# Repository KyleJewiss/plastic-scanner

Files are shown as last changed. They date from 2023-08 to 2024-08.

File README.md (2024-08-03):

# Plastic Scanner

<p align="center">
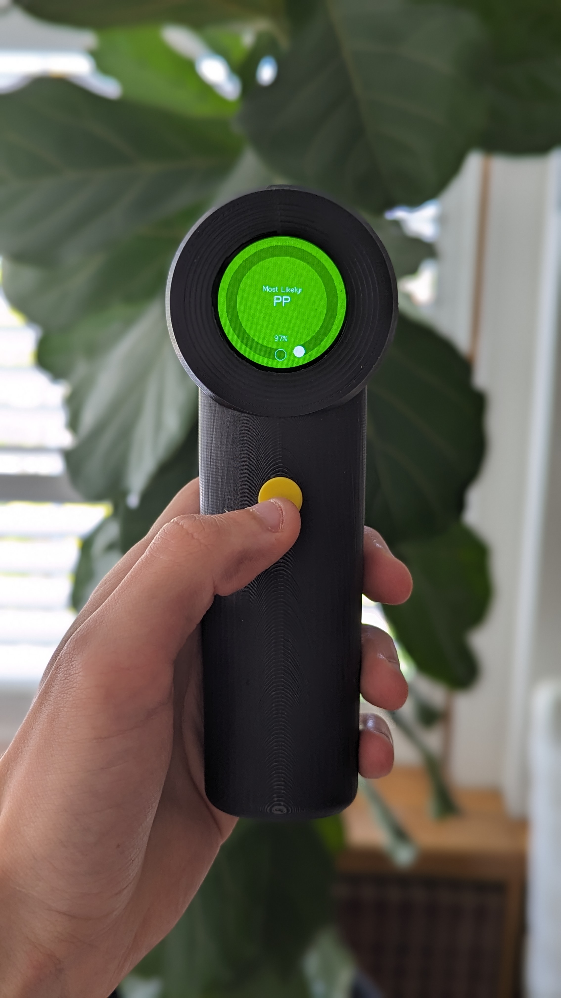
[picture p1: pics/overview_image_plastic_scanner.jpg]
overview_image
  
  overview_image
</p>

## Background
This repo contains the complete work of my Engineering Honours Thesis, 'A Low Cost, Handheld Plastic Identification Device'. This was a continuation of the work produced by the open-source project [Plastic Scanner](https://github.com/Plastic-Scanner). The scanner outlined in this repo can be considered an equal or successor to the [DB2](https://github.com/Plastic-Scanner/DB2.x-Hardware), as this version was used a baseline for the design. This scanner is functional and could be repoduced for testing and development purposes, however it is not adviced to use it in any commercial application. Further development is still needed to improve the reliability of the ML model and the mechanical design.

<p align="center">
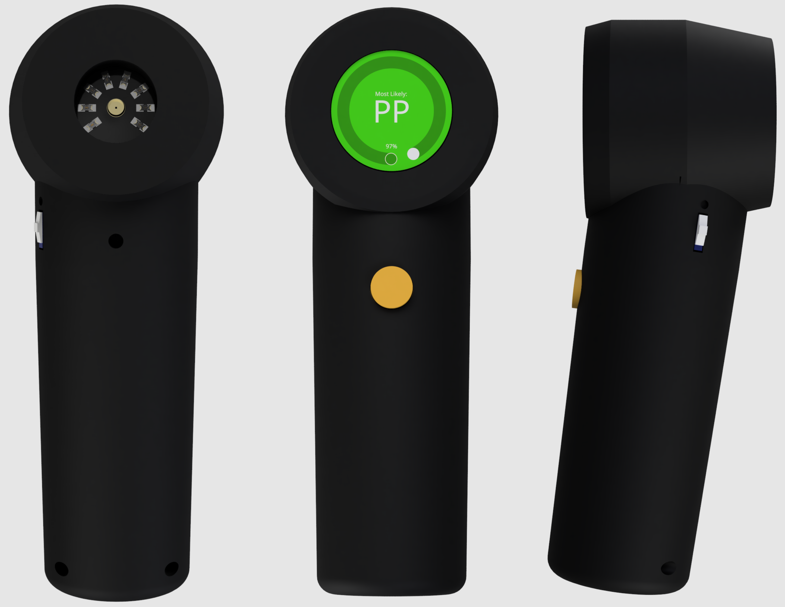
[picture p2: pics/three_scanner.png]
  
</p>

## Introduction
The plastic scanner is a low-cost, handheld device that utilises cheap Infrared (IR) spectroscopic components and a machine learning model to identify plastic polymer types. The device is capable of identifying 7 types of plastics, with a real world accuracy of >80%.

##### Identifiable Plastics
<p align="center">
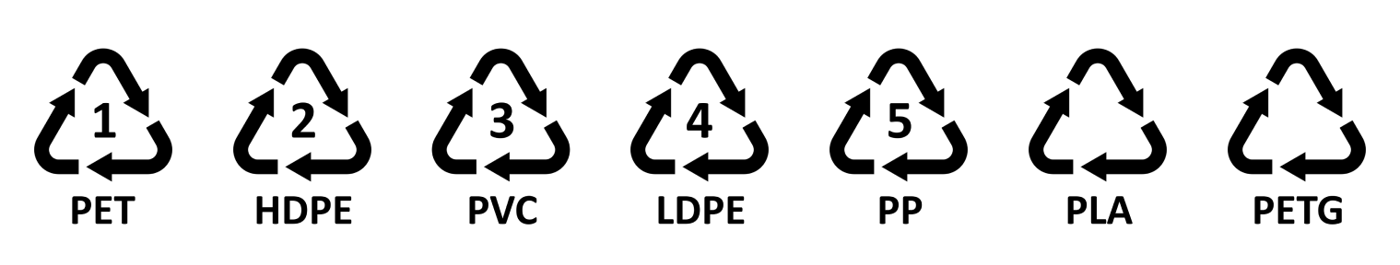
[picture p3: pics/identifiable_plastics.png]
identifiable_plastics
  
</p>

There are some limitations on what it can identify. The scanner is either unable to or struggles to identify plastics that are overly dark/black, very dirty, contain excessive additives, clear or simply too different from the plastic types that were used to train the ML model. For more information on this and much more, checkout [www.plasticscanner.com](www.plasticscanner.com)

## How it works
The scanner works by leveraging principles of [Infrared Spectroscopy](https://en.wikipedia.org/wiki/Infrared_spectroscopy). Plastic polymers tend to have a fairly unqiue reflected waveforms in the IR spectrum, meaning that plastic can be identified/classified by through analysis of these waveforms. The traditional method of achieving this is by using expensive optical filters to obtain the whole reflected intensity waveform. The plastic scanner uses a different approach, it uses relatively inexpensive IR LEDs and a photodiode to obtain the reflected intensities at just a few points. 

<p align="center">
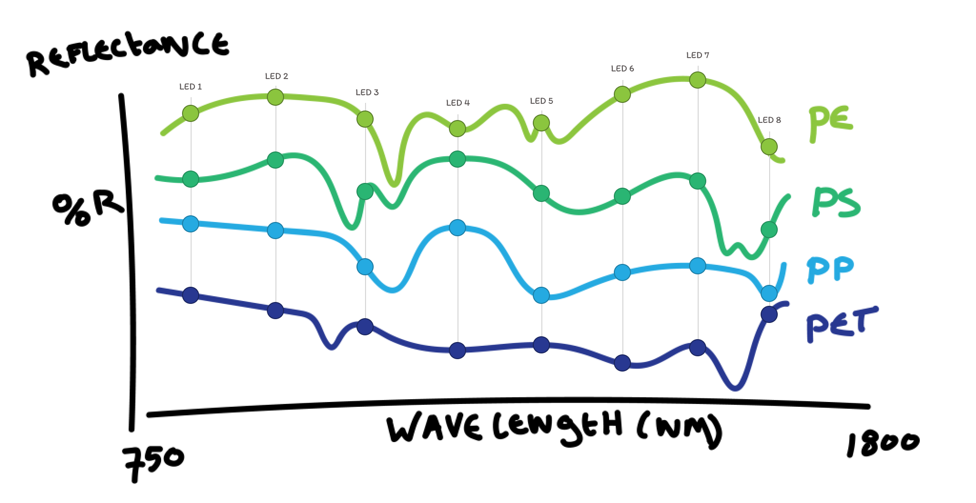
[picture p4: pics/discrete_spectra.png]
discrete_spectra
  
</p>

One at a time, each IR LED is shone onto a plastic sample and an IR photodiode will measure the intensity of the reflected light off of the plastic sample. These 8 intenisty values (one for each LED) can then be fed into an ML model for classification. A novel improvement that this thesis project introduced was to also shine adjacent LEDs at the same time, at half brightness. The light from these two LEDs would then superimpose and provide an additional 7 intensity values, which further improved the accuracy and reliability of the device.

<p align="center">
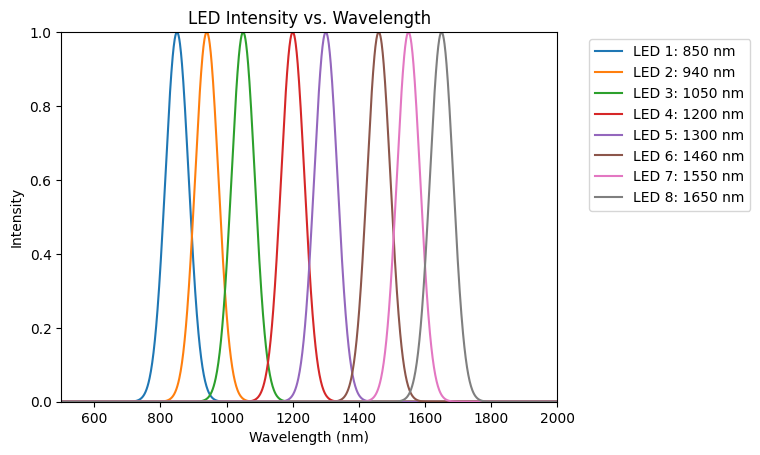
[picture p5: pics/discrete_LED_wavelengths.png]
discrete_LED_wavelengths
  
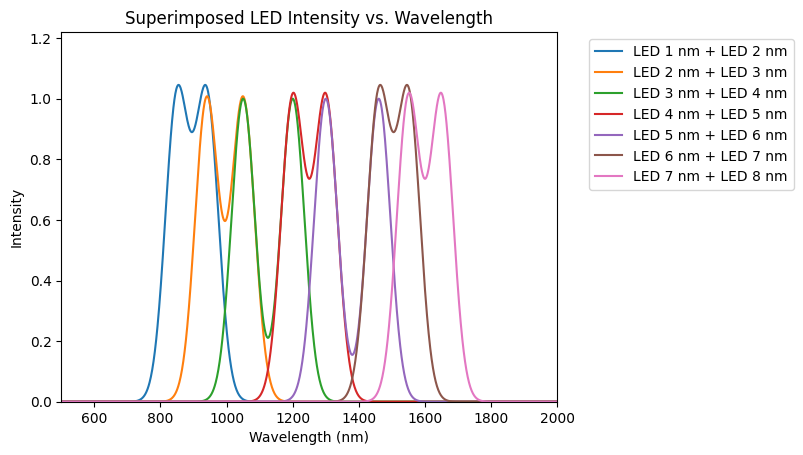
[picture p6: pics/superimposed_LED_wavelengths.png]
superimposed_LED_wavelengths
  
</p>

To identify a piece of plastic, you hold it upto the back of the device (where the LEDs and photodiode is) and press the button. The device will then capture the intensity values, pass them to the ML model and the model will return what it thinks the plastic type most likely is. The round LCD screen on the device will display the predicted polyme type, as well as the associatied percentage likelihood. The following is the 'display guide' for discerning confidence levels.

<p align="center">
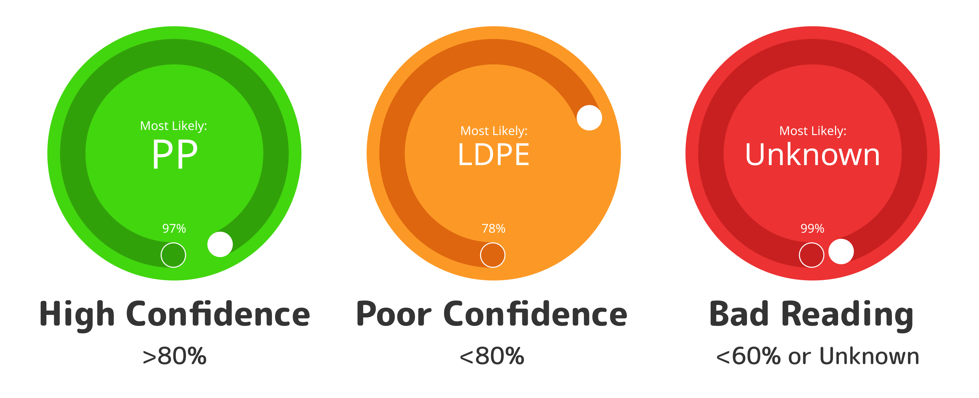
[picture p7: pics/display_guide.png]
display_guide
  
</p>

## Hardware
The custom PCB was designed using EasyEDA, the BOM and GRBL files needed to replicate the board are stored in [hardware/scanninig_PCB](hardware/scanninig_PCB). The structure of the scanner was made in Fusion360 and the CAD files are available. As a brief overview, the device is comprised of the following parts:
- 3D printed enclosure
- Custom scanning PCB
- ESP-32 microcontroller
- 1.28inch Waveshare touchscreen LCD
- 600mAh battery
- Button, switch, USB Typc-C port and fasteners 

<p align="center">
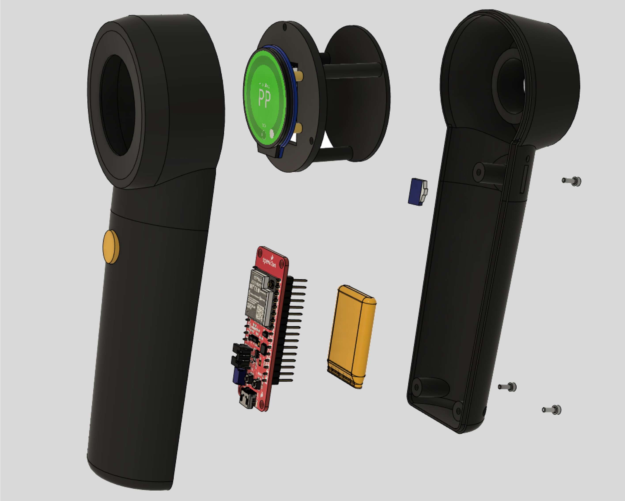
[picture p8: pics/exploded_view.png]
exploded_view
  
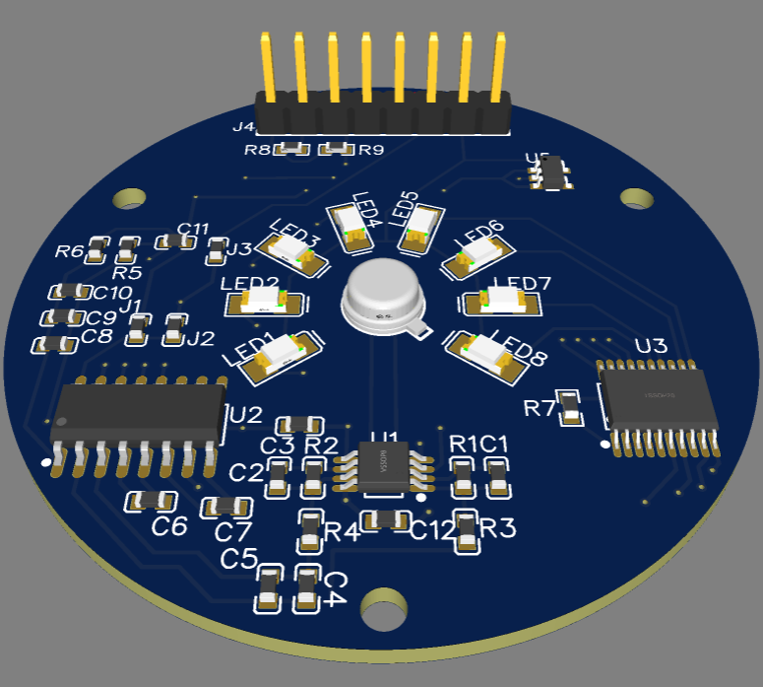
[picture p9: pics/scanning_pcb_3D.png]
scanning_pcb_3D
   
</p>
&nbsp;

## Software
The device itself is controlled by an ESP-32, which was programmed using the PlatformIO IDE and Arduino. Arduino was chosen to gain access to libraries for the LCD screen and simplify development. The code and documentation for the embedded part of this projet can be found in [software/embedded_pio](software/embedded_pio).

The ML model was developed using Tensorflow and Jupyter notebook in a Ubuntu 22.04 docker container. The model developed for this project is a 3-layer feed forward neural network, with ReLU activation. All the data, models and documentation for this project are stored in [software/ml_model](software/ml_model/).

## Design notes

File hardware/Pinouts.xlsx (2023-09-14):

 | working |  | working | working | working
Sense | PIN | Module Pin | Arduino uno | Thing Plus C | Perf Plus C
VCC | 3.3V | VCC | 5V | 3.3V | 3.3V
GND | GND | GND | GND | GND | GND
SDA | 32 | MISO | 12 | 19 | 19
SCL | 33 | MOSI | 11 | 23 | 23
LED RST | 4 | SCLK | 13 | 18 | 18
 |  | LCS_CS | 10 | 14 | 14
 |  | LCS_DC | 7 | 32 | 27
 |  | LCS_RST | 8 | RST | RST
 |  | LCS_BL | 9 | 3.3V | 3.3V
 |  | TP_SDA | SDA | SDA | SDA/21
 |  | TP_SCL | SCL | SCL | SCL/22
 |  | TP_INT | 3 | 15 | 15
 |  | TP_RST | 4 | 33 | -

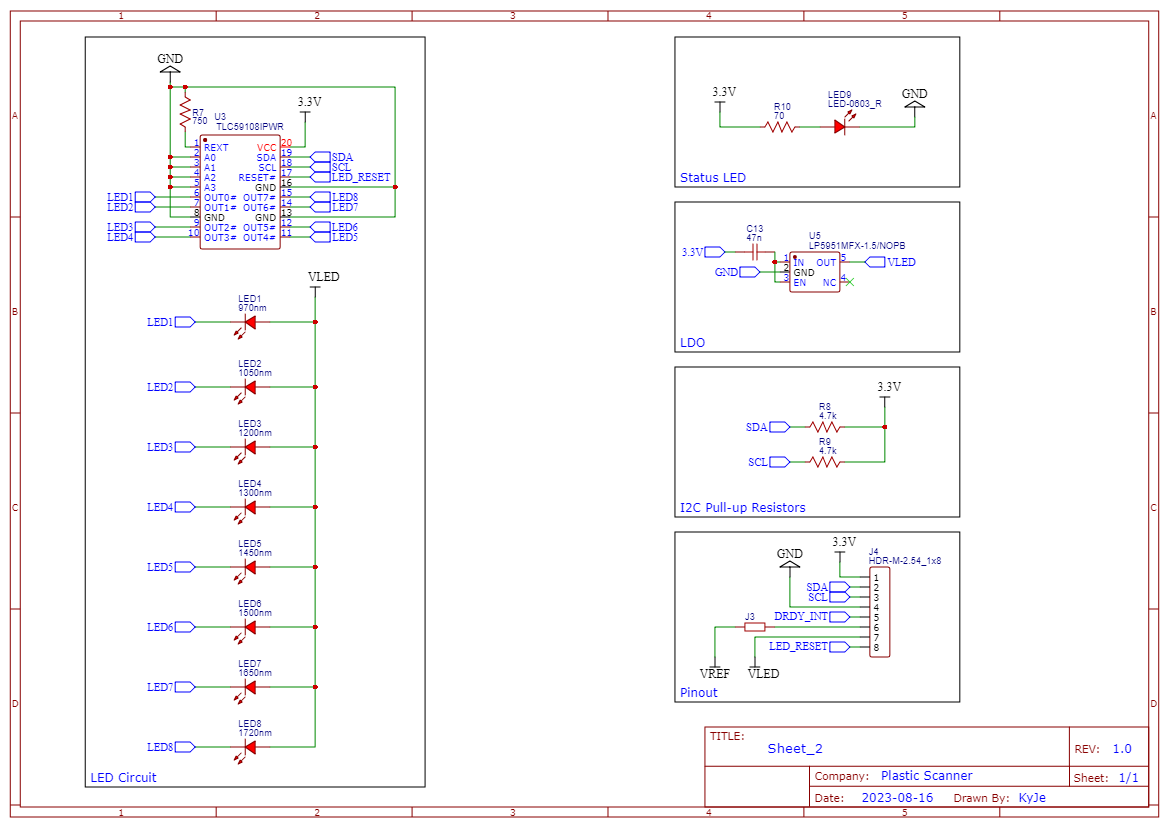
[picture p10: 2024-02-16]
hardware/scanninig_PCB/kyje_plastic_scanner_sheets_prototype_3.2/Sheet_2.png

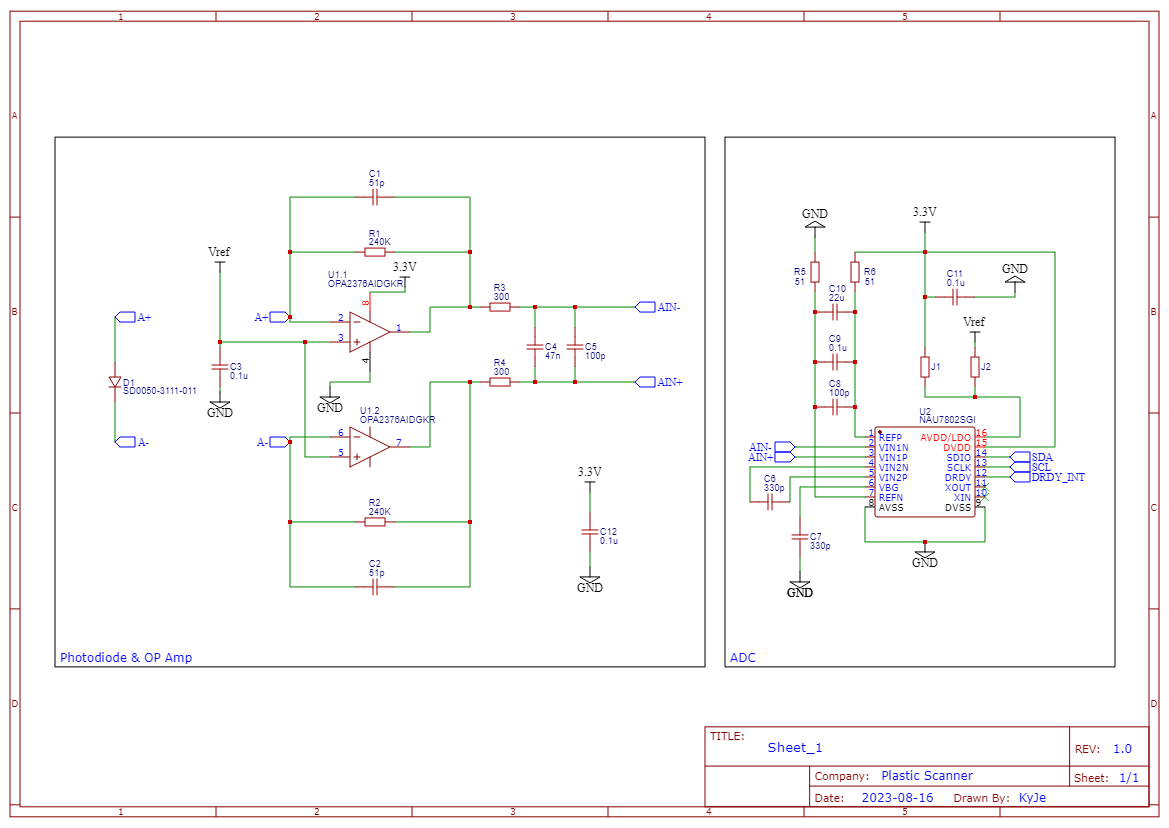
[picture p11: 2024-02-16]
hardware/scanninig_PCB/kyje_plastic_scanner_sheets_prototype_3.2/Sheet_1.png

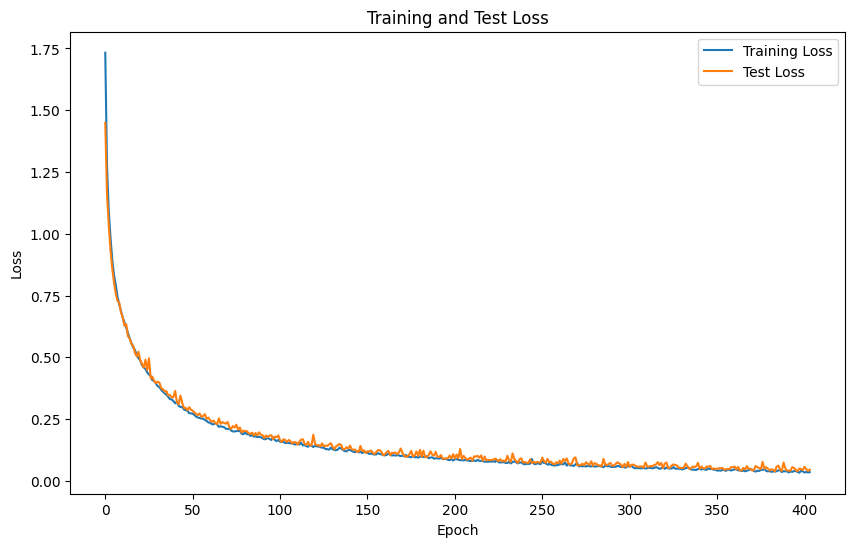
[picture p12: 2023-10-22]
software/analysis/99pEverythingLoss.png

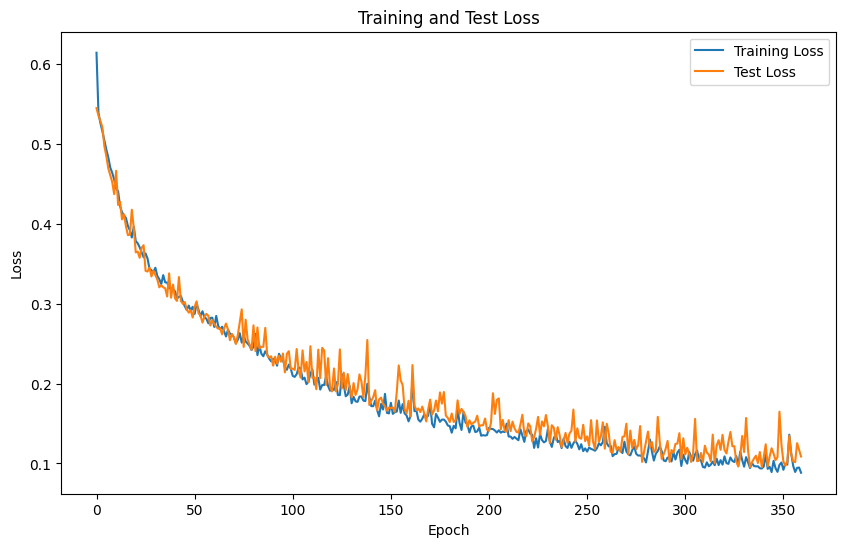
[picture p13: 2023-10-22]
software/analysis/3pEverythingLoss.png

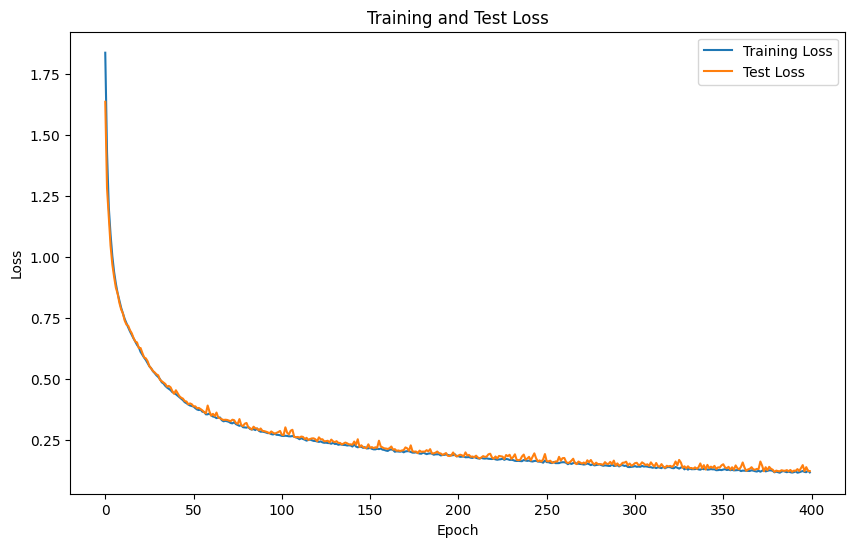
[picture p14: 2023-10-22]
software/analysis/8pEverythingLoss.png

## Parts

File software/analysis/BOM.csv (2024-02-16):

Component | Name | Price (Qty 1) | Price (QTY 100) | Quantity (QTY 1000)
Photodiode | SD0050-3111-011 | $18.89 | $7.33 | $6.07
OP Amp | OPA2376 | $4.66 | $3.21 | $2.18
ADC | NAU7802SGI | $2.65 | $2.02 | $1.37
LED Driver | TLC59108IPWR | $4.56 | $2.53 | $1.72
LED 1 | 850nm | $1.60 | $0.76 | $0.57
LED 2 | 940nm | $0.71 | $0.32 | $0.19
LED 3 | 1050nm | $27.64 | $18.52 | $16.07
LED 4 | 1200nm | $18.81 | $11.58 | $9.59
LED 5 | 1300nm | $18.81 | $11.58 | $9.59
LED 6 | 1460nm | $18.81 | $11.58 | $9.59
LED 7 | 1550nm | $18.81 | $11.58 | $9.59
LED 8 | 1650nm | $31.24 | $20.93 | $19.22
Regulator | LP5951MFX-1.5 | $1.49 | $1.00 | $0.63
LCD | 1.28" Waveshare | $31.36 | $16.02 | $11.54
Microcontroller | ESP32 - WeMos | $9.60 | $9.41 | $8.83
Connector | USB C | $0.24 | $0.24 | $0.20
Battery | 800mAh 3.7V Lipo | $1.60 | $1.50 | $1.45
Power Switch | SPDT Switch | $2.50 | $2.25 | $2.00
Push Button | Tactile Button | $0.40 | $0.32 | $0.16
3D Print | - | $0.95 | $0.95 | $0.95 |  |  | 5 | $68.66 | $343.30 | $18.15 | $361.45 | $72.29
Vibration Motor | Piezoelectric Actuator | $1.95 | $0.96 | $0.64 |  |  | 100 | $134.59 | $13,459.00 | $105.33 | $13,564.33 | $135.64
 |  | $217.28 | $134.59 | $112.15 |  |  | 1000 | $112.15 | $112,150.00 | $519.32 | $112,669.32 | $112.67
 |  |  |  |  |  |  | 5 | $68.66 | $343.30 | $18.15 | $361.45 | $72.29
 |  |  |  |  |  |  | 100 | $43.42 | $4,342.00 | $105.33 | $4,447.33 | $44.47
 |  |  |  |  |  |  | 1000 | $35.91 | $35,910.00 | $519.32 | $36,429.32 | $36.43
PCB Manufacture | Price | Shipping Price | Total | Per Piece
Qty 5 | $3.17 | $2.28 | $5.45 | $1.09
Qty 100 | $18.57 | $29.63 | $48.20 | $0.48
Qty 1000 | $174.41 | $137.96 | $312.37 | $0.31
PCB Assembly | Price | Per Piece
Qty 5 | 12.7 | $2.54 |  | $5.45 | 12.7 | $18.15 | $3.63
Qty 100 | 57.13 | $0.57 |  | $48.20 | 57.13 | $105.33 | $1.05
Qty 1000 | 206.95 | $0.21 |  | $312.37 | 206.95 | $519.32 | $0.52

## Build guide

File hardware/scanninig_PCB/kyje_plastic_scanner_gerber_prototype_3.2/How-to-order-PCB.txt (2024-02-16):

How to Order PCB

Please refer to:
https://docs.easyeda.com/en/PCB/Order-PCB

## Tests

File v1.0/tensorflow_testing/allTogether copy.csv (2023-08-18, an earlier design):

IR_Wavelength_1 | IR_Wavelength_2 | IR_Wavelength_3 | IR_Wavelength_4 | IR_Wavelength_5 | IR_Wavelength_6 | IR_Wavelength_7 | IR_Wavelength_8 | Plastic_Type
1168.67 | 4554.33 | 9864.67 | 14126.33 | 18922.67 | 16432.33 | 9342.67 | 5869 | HDPE
1178.67 | 4009 | 7861.33 | 10958.33 | 14438 | 12899 | 7541.33 | 5074.33 | HDPE
1237.33 | 3407 | 6256 | 8488.33 | 11974.67 | 10385.67 | 6176 | 4495.67 | HDPE
1285.33 | 3907.67 | 7551.33 | 10499 | 13880.67 | 12162.33 | 7402 | 4970.33 | HDPE
765.33 | 4119.67 | 9332 | 12238.33 | 18396 | 18587 | 10390 | 5871.67 | HDPE
1230 | 3366.33 | 6288 | 8667 | 12524.67 | 11265 | 6674 | 4764.33 | HDPE
787.33 | 3385.67 | 8155.33 | 11215 | 16360 | 15614.33 | 8599.33 | 5225.67 | HDPE
689.33 | 4022.33 | 10292.67 | 14646.33 | 20452.67 | 18073.67 | 9078 | 5285 | HDPE
722.67 | 3890.33 | 9708.67 | 13236.33 | 18270 | 16573.67 | 8448 | 4963.67 | HDPE
1188.67 | 2703 | 5336 | 7977 | 11158 | 9978.33 | 6612 | 4681 | HDPE
999.33 | 4285 | 8785.33 | 11508.33 | 15999.33 | 14865 | 8645.33 | 5851.67 | HDPE
717.33 | 5537.67 | 13770.67 | 19276.33 | 24978.67 | 21049 | 10705.33 | 6391.67 | HDPE
1080 | 4439.67 | 8862.67 | 12323 | 16205.33 | 14113 | 7787.33 | 4969.67 | HDPE
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

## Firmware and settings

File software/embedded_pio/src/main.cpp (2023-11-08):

/*Display Code*/
#include <Arduino.h>
#include <Wire.h>
#include <Adafruit_NAU7802.h>
#include <BluetoothSerial.h>
#include "TLC.h"
#include "LCD.h"
#include <CST816S.h>

CST816S touch(21, 22, 26, 15); // sda, scl, rst, irq
bool allow = 0;

Adafruit_NAU7802 nau;

BluetoothSerial SerialBT;
bool bluth_tog = 0;

long startT = 0;

uint64_t sensor_readings[15];

const uint8_t buttonPin = 17;

void probe(bool probeNumber)
{

  if (!probeNumber)
  {
    startT = millis();
  }
  else
  {
    long stopT = millis();
    Serial.println(stopT - startT);
  }
}

void flushReadings(uint8_t amount)
{
  for (uint8_t i = 0; i < amount; i++)
  {
    while (!nau.available())
      delay(1);
    nau.read();
  }
}

int getNAUReading()
{
  while (!nau.available())
  {
    delay(1);
  }
  return nau.read();
}

void initNAU7802()
{
  if (!nau.begin(&Wire1))
  {
    Serial.println("Failed to find NAU7802");
  }
  nau.setGain(NAU7802_GAIN_32);
  nau.setLDO(NAU7802_EXTERNAL);
  nau.setRate(NAU7802_RATE_320SPS);

  // Take 10 readings to flush out readings
  flushReadings(10);
}

void initSenseModule()
{
  initTLC(0x40, 4); // Initialise TLC LED Driver
  initNAU7802();    // Initialise the ADC
  delay(500);       // Allow time for the initNAU to work,
}

double getAvgReading(uint8_t repeats = 1)
{
  double adcReadings = 0;
  flushReadings(5);

  for (uint8_t i = 0; i < repeats; i++)
  {
    adcReadings += getNAUReading();
  }

  adcReadings = (adcReadings / repeats);

  return adcReadings;
}

void scanWithAllLEDs()
{
  for (int LED = 0; LED < 8; LED++)
  {
    int ref = getNAUReading();
    setBrightness(LED, 0xff);
    delay(15);
    int relReading = getNAUReading() - ref;
    Serial.print(relReading);
    Serial.print(",");
    setBrightness(LED, 0x00);
    delay(15);
    sensor_readings[LED] = relReading;
  }

  // Get the reflectance values for combinations of the 8 LED's
  for (int LED = 0; LED < 7; LED++)
  {
    int ref = getNAUReading();
    setBrightness(LED, 0x7f);
    setBrightness(LED + 1, 0x7f);
    delay(15);
    int relReading = getNAUReading() - ref;
    Serial.print(relReading);
    if (LED < 6)
    {
      Serial.print(",");
    }
    setBrightness(LED, 0x00);
    setBrightness(LED + 1, 0x00);
    delay(15);

    sensor_readings[LED + 8] = relReading;
  }
  Serial.println();
}

void intensityScan()
{
  int ref = getNAUReading();

  for (int i = 16; i < 64; i++)
  {
    for (int LED = 0; LED < 8; LED++)
    {
      setBrightness(LED, i);
      delay(2);
    }

    delay(2);
    int relReading = getNAUReading() - ref;
    Serial.print(relReading);
    Serial.print(',');
  }

  for (int i = 62; i > 16; i--)
  {
    for (int LED = 0; LED < 8; LED++)
    {
      setBrightness(LED, i);
      delay(2);
    }

    delay(2);
    int relReading = getNAUReading() - ref;
    Serial.print(relReading);
    Serial.print(',');
  }
  Serial.println();
}

void setup()
{
  Serial.begin(115200);
  Serial.println("Initialising LCD");
  initLCD();

  startingDevicePage();

  Serial.println("Initialising Touchscreen");
  touch.begin();

  Serial.println("Initialising Sense Module");
  Wire1.begin(32, 33);
  initSenseModule();
  setupLEDOutput(2); // This allows the "setLEDBrightness" function. Remove if not in use

  pinMode(12, OUTPUT);
  pinMode(buttonPin, INPUT);

  startPage();
  SerialBT.begin("POLY_ID"); // Bluetooth device name
  if (SerialBT.connected())
  {
    Serial.println("Bluetooth Connected");
  }
  else
  {
    Serial.println("Bluetooth Not Connected");
  }
  Serial.println("All good");
}

void loop()
{
  /* The touchscreen registeres a gesture as long as a finger is on the screen. So to avoid registering the same gesture...
  multiple times over we only allow a gesture to register directly after a "NONE" gesture, ensuring it only runs once.*/
  if (touch.gesture() == "NONE")
  {
    allow = 1;
  }

  int buttonState = digitalRead(buttonPin);

  // Run code based on the gesture detected by the touch screen
  if (touch.available() && allow)
  {
    allow = 0;

    if (touch.gesture() == "SINGLE CLICK")
    {
      int relreading = getNAUReading();

      for (int LED = 0; LED < 8; LED++)
      {
        Serial.print("LED");
        Serial.println(LED);
        for (int i = 0; i < 50; i += 1)
        {
          setBrightness(LED, 0xff);
          delay(i);

          while (!nau.available())
          {
          }
          Serial.print(getNAUReading() - relreading);
          Serial.print(",");
          setBrightness(LED, 0x00);
          delay(100);
        }

        Serial.println();
      }
    }
    else if (touch.gesture() == "SWIPE UP")
    {
      bluth_tog = 1;
      buzz(150);
      delay(50);
      buzz(150);
    }
    else if (touch.gesture() == "SWIPE DOWN")
    {
      bluth_tog = 0;
      buzz(150);
      delay(50);
      buzz(150);
    }
  }

  // Serial Method
  if (buttonState == HIGH)
  {
    loadingpage();
    if (bluth_tog == 0)
    {
      scanWithAllLEDs();

      delay(1000);
      String receivedData = "";
      String receivedPlasticType = "";
      float receivedLikelihood = 0.0;
      while (Serial.available() > 0)
      {
        char receivedChar = Serial.read();

        if (receivedChar == ',')
        {
          // The comma acts as a delimiter; process the received data
          receivedPlasticType = receivedData;
          receivedData = ""; // Reset for the next data field
        }
        else
        {
          receivedData += receivedChar;
        }
      }
      printPlasticType(receivedPlasticType, receivedData);
    }

    else
    {
      // Bluetooth method
      if (bluth_tog == 1)
      {
        int startTime = millis();
        scanWithAllLEDs();

        Serial.println("bluetooth method");

        // Send sensor readings over SerialBT
        for (int value = 0; value < 15; value++)
        {
          SerialBT.print(sensor_readings[value]);
          if (value < 14)
          {
            SerialBT.print(","); // Add a comma as a separator, except for the last value
          }
        }
        SerialBT.println();

        delay(1000);
        String receivedData = "";
        String receivedPlasticType = "";
        float receivedLikelihood = 0.0;
        while (SerialBT.available() > 0)
        {
          char receivedChar = SerialBT.read();

          if (receivedChar == ',')
          {
            // The comma acts as a delimiter; process the received data
            receivedPlasticType = receivedData;
            receivedData = ""; // Reset for the next data field
          }
          else
          {
            receivedData += receivedChar;
          }
        }
        printPlasticType(receivedPlasticType, receivedData);
      }
    }
  }
}

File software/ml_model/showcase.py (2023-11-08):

print("starting")

from tensorflow.keras.models import load_model
import pandas as pd
import numpy as np
import tensorflow as tf
import matplotlib.pyplot as plt
from sklearn.model_selection import train_test_split
from sklearn.preprocessing import LabelEncoder
from keras.callbacks import EarlyStopping
import serial

# Load the model
model = load_model("15_point_showcase_model.keras")

# Open the serial port
ser = serial.Serial('COM5', baudrate=9600)  # Adjust the baudrate as needed

# Initialize a variable to store the received data
received_data = ""

# Get labels from csv file
data = pd.read_csv("15_point_showcase.csv")
X = data.drop(columns=["Material_Type"])
y = data["Material_Type"]
label_encoder = LabelEncoder()
y_encoded = label_encoder.fit_transform(y)

print("ready")

try:
    while True:
        # Read a line of data from the serial port (assuming data is sent as lines)
        line = ser.readline().decode('utf-8').strip()

        # Split the received data into a list of numbers using a comma as the delimiter
        data_values = [float(val) for val in line.split(',')]

        print(line)
        
        # Normalize the data values if needed
        normalized_data = [(val - 0) / (8410000 - 0) for val in data_values]
        
        # Make predictions on the normalized data
        predictions = model.predict([normalized_data])  # Convert normalized_data to a list
        
        # Format the model so that its easier to read in terminal 
        formatted_predictions = np.around(predictions, 4)

        # Get the top prediction
        top_prediction = np.argmax(predictions)

        top_plastic_type = label_encoder.inverse_transform([top_prediction])[0]

        likelihood = predictions[0][top_prediction] * 100

        # Display the prediction for manual input
        print(f"Manual Input Prediction:")
        print(f"  Prediction: {top_plastic_type} with {likelihood:.2f}% likelihood")

        received_data = ""

        # Send the top plastic type back over serial
        likelihood_str = round(likelihood)-1
        data_to_send = f"{top_plastic_type},{likelihood_str}"  # Combine the data fields with a comma delimiter
        ser.write(data_to_send.encode('utf-8'))

except KeyboardInterrupt:
    # Handle Ctrl+C to stop the loop gracefully
    pass

finally:
    # Close the serial port when done
    ser.close()

# Now, you can use the 'received_data' variable for further processing
print("total data:\n", received_data)

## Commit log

2023-07-25 working sensor & adc
2023-08-01 All features on the PCB are functional
2023-08-18 Started development of webGUI. Refactored main.cpp
    [allTogether copy.csv, allTogether.csv, clustered_data.csv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]
2023-08-22 92% accurate model
    [Alltogether2.4v.csv, allTogether copy.csv, allTogether.csv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]
2023-08-29 added prelim data for exposure model. Got touch screen working
    [PP.csv, hdpe.csv, ldpe.csv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]
2023-09-04 Working integration of touchscreen and sense module
    [Alltogether2.4v - Copy.csv, Alltogether2.4v8Point.csv, Alltogether2.4vDivided.csv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]
2023-09-14 Optimised scanning code. 15 values in 0.5s
    [Pinouts.xlsx]
2023-09-14 added new scan data for v1.1 scanner
    [AllTogether.xlsx, HDPE.csv, LDPE.csv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]
2023-09-17 97%+ accurate model. Combined LDPE & HDPE. Added 'other' category to data set
    [AllTogether.csv, AllTogether.xlsx, AllTogetherNewPP.csv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]
2023-09-18 improved HDPEvsLDPE model. Tested 8P model ~60%
    [AllTogether8Ptest.csv, HDPEvsLDPE.csv, resampled_dataset8Ptest.csv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]
2023-09-20 Improved reliability of scans but adding dataset of scans from more angles
    [AllTogether.csv, AllTogetherHvL.csv, AllTogetherPE.csv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]
2023-09-30 added PET to the model
    [AllTogether.csv, AllTogether8Ptest.csv, AllTogetherEverything.csv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]
2023-09-30 added PVC to the model. Still 99% accuracy
    [AllTogetherVVPP.csv, AllTogethertest.csv, HDPE3.csv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]
2023-10-12 added bluetooth support for the device
    [AllTogetherHvL.csv, AllTogetherHvL2.csv, AllTogether_30_09.csv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]
2023-10-18 made improvements to user interface. Started new dataset for the new physical body
    [AllTogether.csv, AllTogether_30_09.csv, HDPE.csv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]
2023-10-19 calculated pcb accuracies
    [AllTogether_30_09.csv, accuracy dark.csv, accuracy light.csv]
2023-10-21 made more analysis docs
    [15point_21_10_everything.csv, 3point.csv, 3point21_10.csv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]
2023-10-22 more work on analysis
    [3point21_10 - Copy.csv]
2023-10-22 adding analysis dir
    [accuracy dark.csv, accuracy light.csv]
2023-10-22 trying again
    [BOM.csv, accuracy dark.csv, accuracy light.csv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]
2023-10-28 added real world testing
    [15point_26_10_everything.csv, 3point21_10_recy.csv, LDPE.csv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]
2023-11-08 added dataset4
    [15_point_showcase.csv, 15point_26_10_everything.csv, AllTogether.csv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]
2024-02-16 refactor: made the code a tiny little bit better
    [15_point_showcase.csv, 15point_21_10_everything.csv, 15point_26_10_everything.csv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]
2024-02-16 feat: added the most recent hardware files
    [15_point_showcase.csv, 15point_26_10_everything.csv, AllTogether.csv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]
2024-02-20 feat: added BOM
    [Drill_NPTH_Through.DRL, Drill_PTH_Through.DRL, Drill_PTH_Through_Via.DRL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]
2024-08-03 docs: updated the readme (#1)
    * feat: added docker container to simplify ml development
    * docs: updated readme
    * docs: further added to readme
    * chore: missed stuff
    * docs: updated readme
    * chore: added cad files
    ---------
    [Drill_NPTH_Through.DRL, Drill_PTH_Through.DRL, Drill_PTH_Through_Via.DRL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]
